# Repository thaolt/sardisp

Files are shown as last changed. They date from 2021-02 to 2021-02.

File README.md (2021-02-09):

# sardisp

## Content

  * [What is it?](#what-is-it)
  * [Installation](#installation)
    + [Windows](#windows)
    + [Linux](#linux)
  * [How to use](#how-to-use)
    + [avrdude](#avrdude)
    + [AVRDUDESS](#avrdudess)
    + [Arduino IDE](#arduino-ide)
  * [Tools](#tools)
  * [Schematic](#schematic)
  * [Perf-board implement](#perf-board-implement)
  * [References](#references)

## What is it?

DIY Simple Arduino In-System-Programmer (aka perf-board USBasp clone)

## Installation

### Windows

**Driver installation**

Please read:

* https://zadig.akeo.ie/
* https://electronics.stackexchange.com/questions/416714/avrdude-does-not-recognize-usbasp-device/417509#417509

Or download:

https://raw.githubusercontent.com/thaolt/sardisp/master/drivers/usbasp_signed.zip

### Linux

Linux doesn't need driver installation

However, it would be more convenient to allow current user access USB instead of execute commands under `root` or `sudo`

If you ever run these steps before, they don't need to be executed again

`$USER` is your current login name on your machine

```
sudo adduser $USER dialout
sudo adduser $USER tty
sudo adduser $USER plugdev
```

Then log out of current desktop session and log in again, it's done.

## How to use

Any software / IDE support USBasp programmer

### avrdude

```
avrdude -u -c usbasp -P usb ...
```
### AVRDUDESS

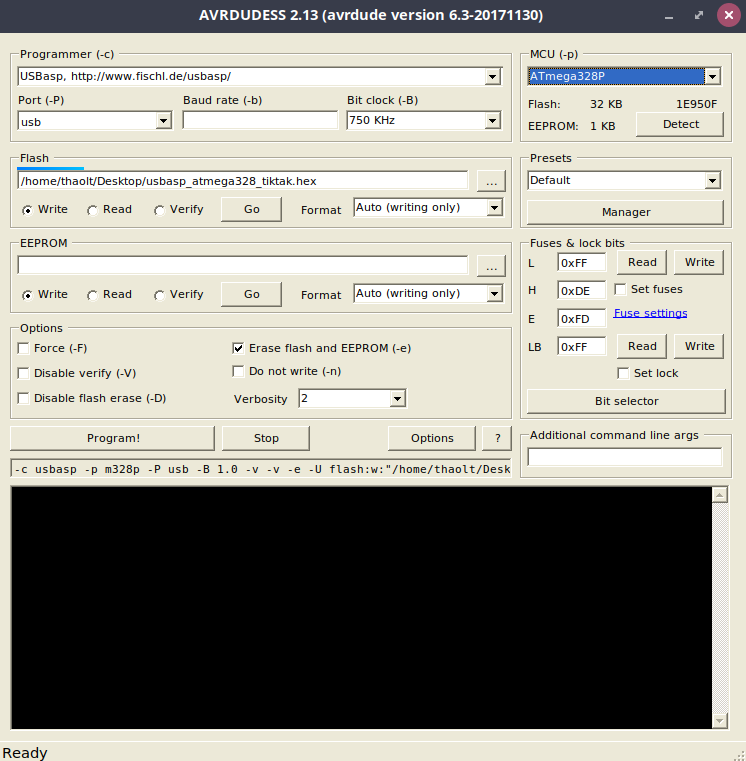
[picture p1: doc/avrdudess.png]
avrdudess usbasp


### Arduino IDE

`Tools` > `Programmer` > `USBasp`

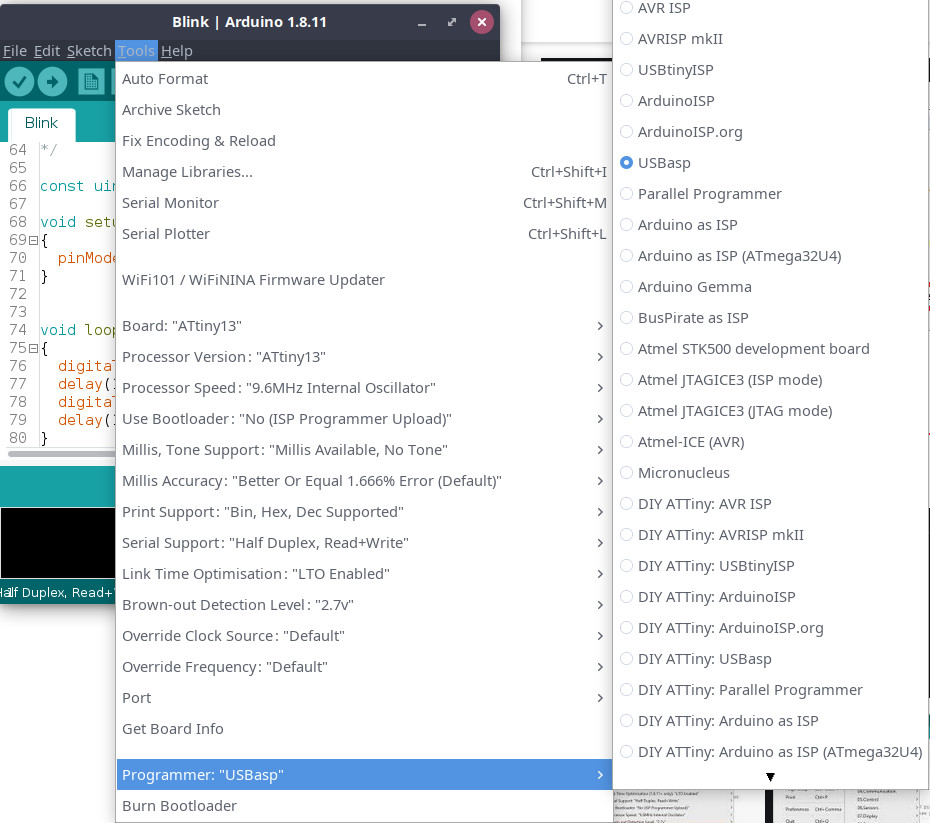
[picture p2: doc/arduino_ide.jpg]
arduino ide usbasp


## Tools

* **Kicad PCB** software is used for making perf-board design easier. https://kicad.org/
* **AVRDUDESS** is a GUI software for avrdude for flashing the firmware, works on Windows, Mac, Linux. https://blog.zakkemble.net/avrdudess-a-gui-for-avrdude/

## Schematic

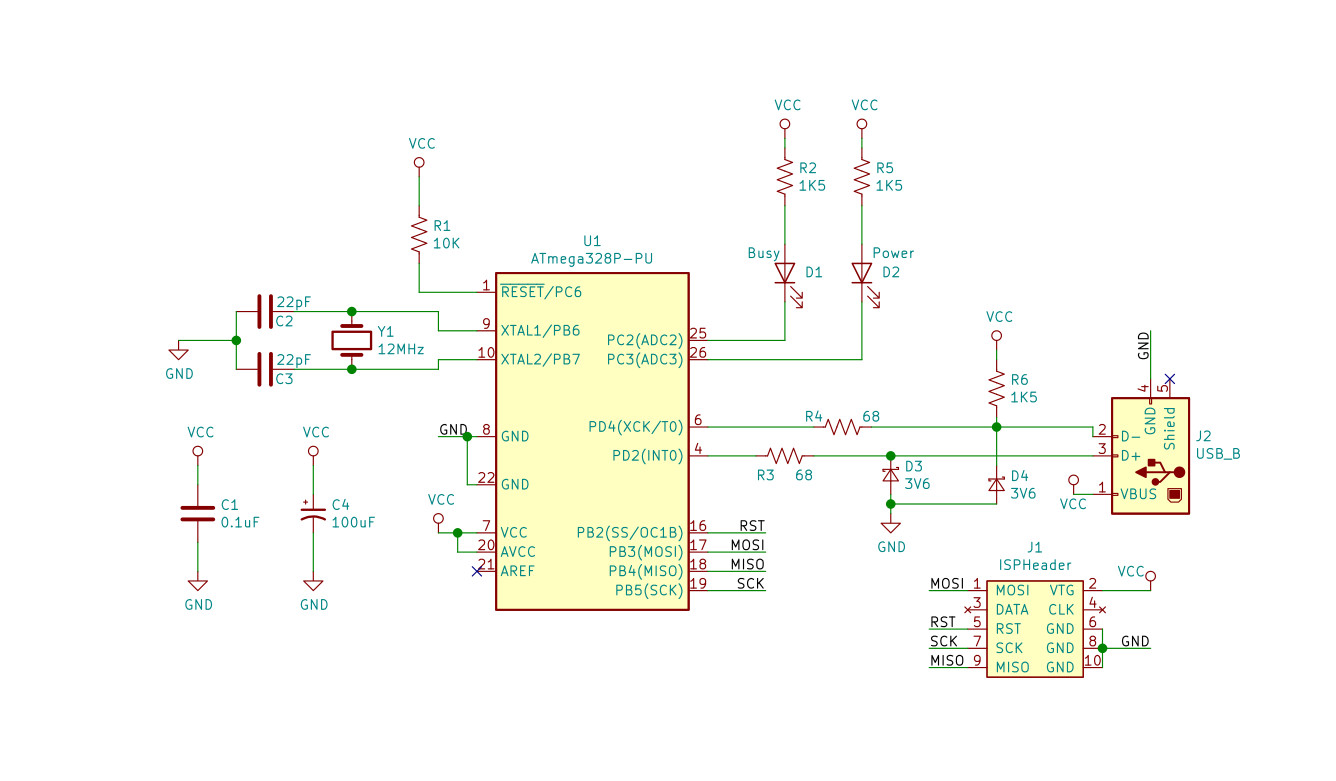
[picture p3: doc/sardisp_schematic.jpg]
sardisp schematic


## Perf-board implement

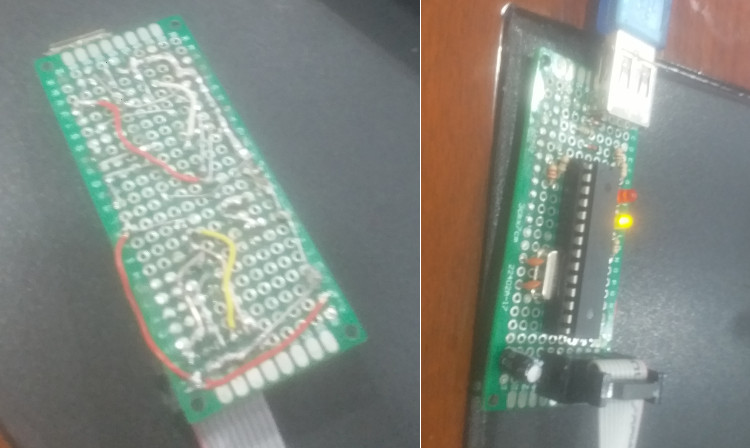
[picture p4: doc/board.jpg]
sardisp board


## References

* https://www.fischl.de/usbasp/
* https://github.com/obdev/v-usb
* https://hackaday.io/project/27401-creative-repairs-and-hacks/log/156127-replacing-an-atmega8-with-a-atmega328p-on-a-usbasp-board
* https://tiktakx.wordpress.com/tag/diy-usbasp-using-atmega-328/

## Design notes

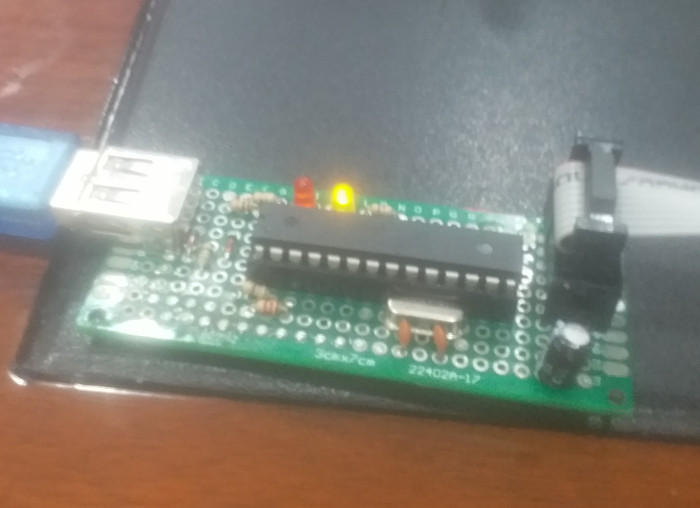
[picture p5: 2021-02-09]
doc/boardup.jpg

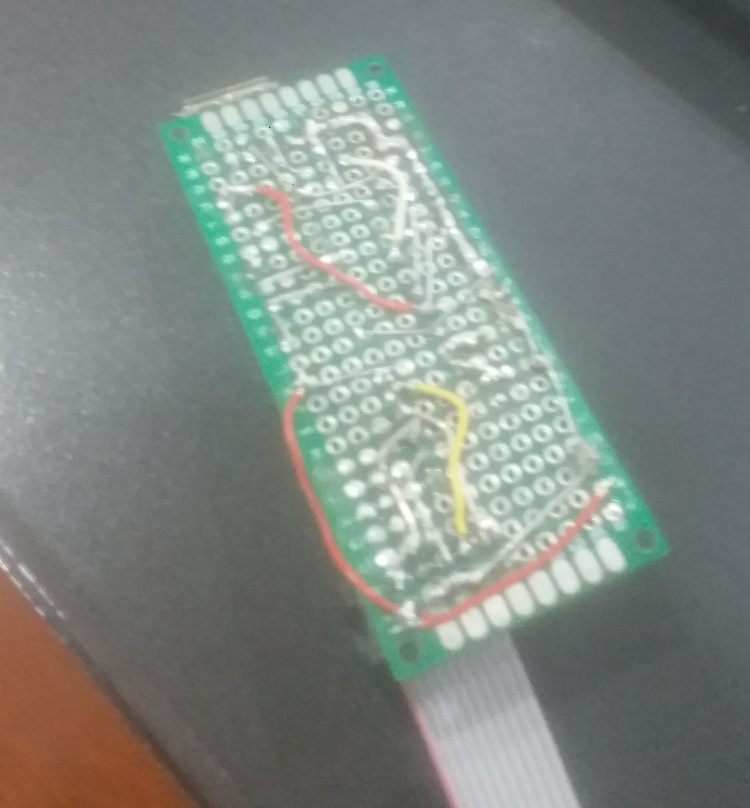
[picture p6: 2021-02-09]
doc/boarddown.jpg

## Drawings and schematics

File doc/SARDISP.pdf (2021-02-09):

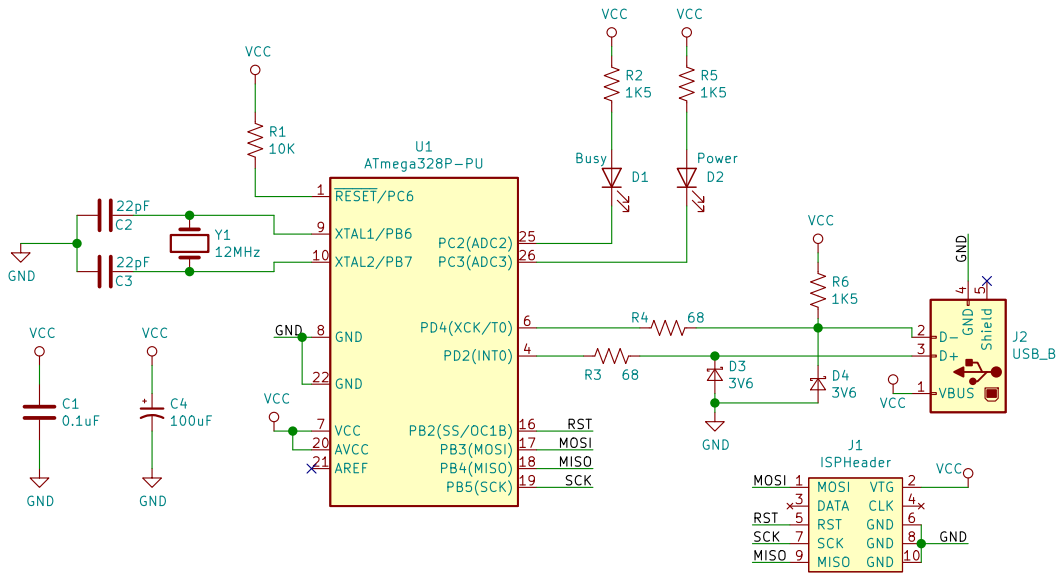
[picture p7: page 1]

Id: 1/1 Title: File: SARDISP.sch Sheet: /

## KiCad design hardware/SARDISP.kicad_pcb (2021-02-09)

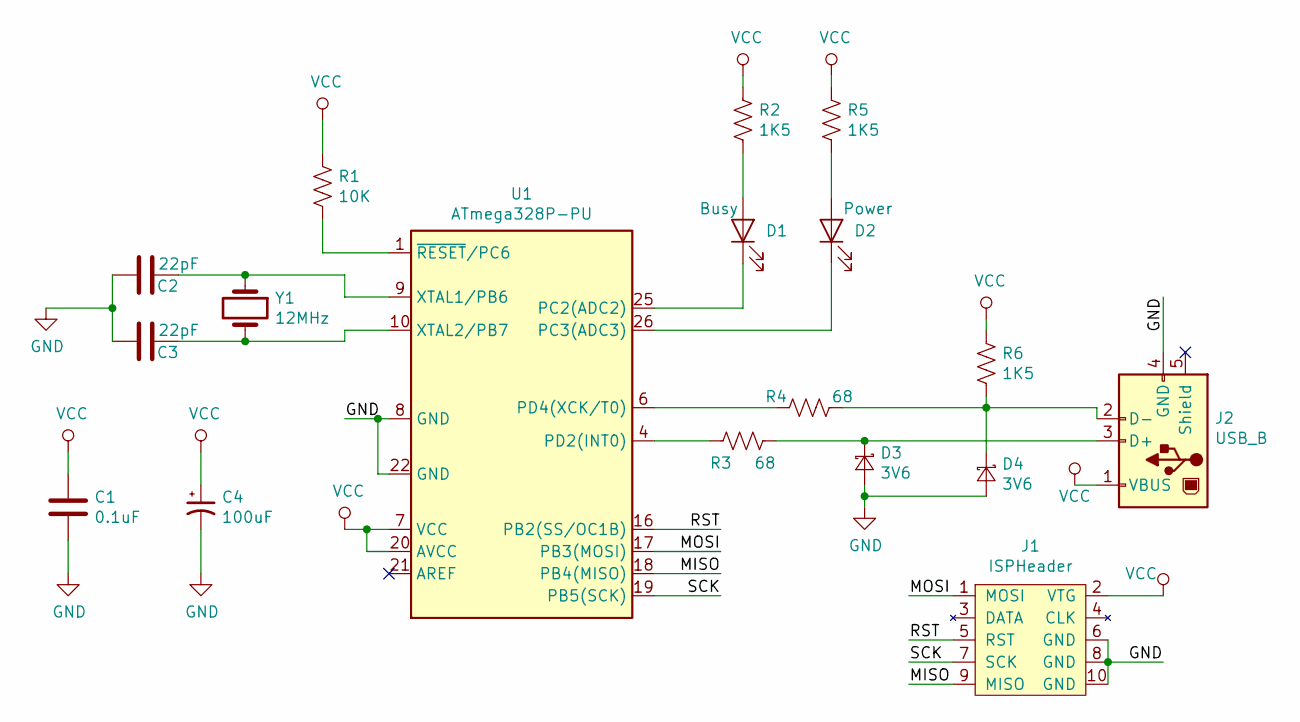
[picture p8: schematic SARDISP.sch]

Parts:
C1: 0.1uF; C_Disc_D3.0mm_W1.6mm_P2.50mm
C2, C3: 22pF; C_Disc_D3.0mm_W1.6mm_P2.50mm
C4: 100uF; CP_Radial_D5.0mm_P2.50mm
D1: Busy; LED_D3.0mm
D2: Power; LED_D3.0mm
D3, D4: 3V6; D_A-405_P7.62mm_Horizontal
J1: ISPHeader; IDC-Header_2x05_P2.54mm_Horizontal
J2: USB_B; USB_A_Stewart_SS-52100-001_Horizontal
R1: 10K; R_Axial_DIN0204_L3.6mm_D1.6mm_P7.62mm_Horizontal
R2, R5, R6: 1K5; R_Axial_DIN0204_L3.6mm_D1.6mm_P7.62mm_Horizontal
R3, R4: 68; R_Axial_DIN0204_L3.6mm_D1.6mm_P7.62mm_Horizontal
U1: ATmega328P-PU; DIP-28_W7.62mm
Y1: 12MHz; Crystal_HC18-U_Vertical

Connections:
/MISO: J1.9 (MISO), U1.18 (PB4(MISO))
/MOSI: J1.1 (MOSI), U1.17 (PB3(MOSI))
/RST: J1.5 (RST), U1.16 (PB2(SS/OC1B))
/SCK: J1.7 (SCK), U1.19 (PB5(SCK))
GND: C1.2, C2.2, C3.2, C4.2, D3.2 (A), D4.2 (A), J1.6 (GND), J1.8 (GND), J1.10 (GND), J2.4 (GND), U1.8 (GND), U1.22 (GND)
unnamed: C2.1, U1.9 (XTAL1/PB6), Y1.1
unnamed: C3.1, U1.10 (XTAL2/PB7), Y1.2
unnamed: D1.1 (K), U1.25 (PC2(ADC2))
unnamed: D1.2 (A), R2.2
unnamed: D2.1 (K), U1.26 (PC3(ADC3))
unnamed: D2.2 (A), R5.2
unnamed: D3.1 (K), J2.3 (D+), R3.1
unnamed: D4.1 (K), J2.2 (D-), R4.2, R6.2
unnamed: R1.2, U1.1 (~RESET~/PC6)
unnamed: R3.2, U1.4 (PD2(INT0))
unnamed: R4.1, U1.6 (PD4(XCK/T0))
VCC: C1.1, C4.1, J1.2 (VTG), J2.1 (VBUS), R1.1, R2.1, R5.1, R6.1, U1.7 (VCC), U1.20 (AVCC)

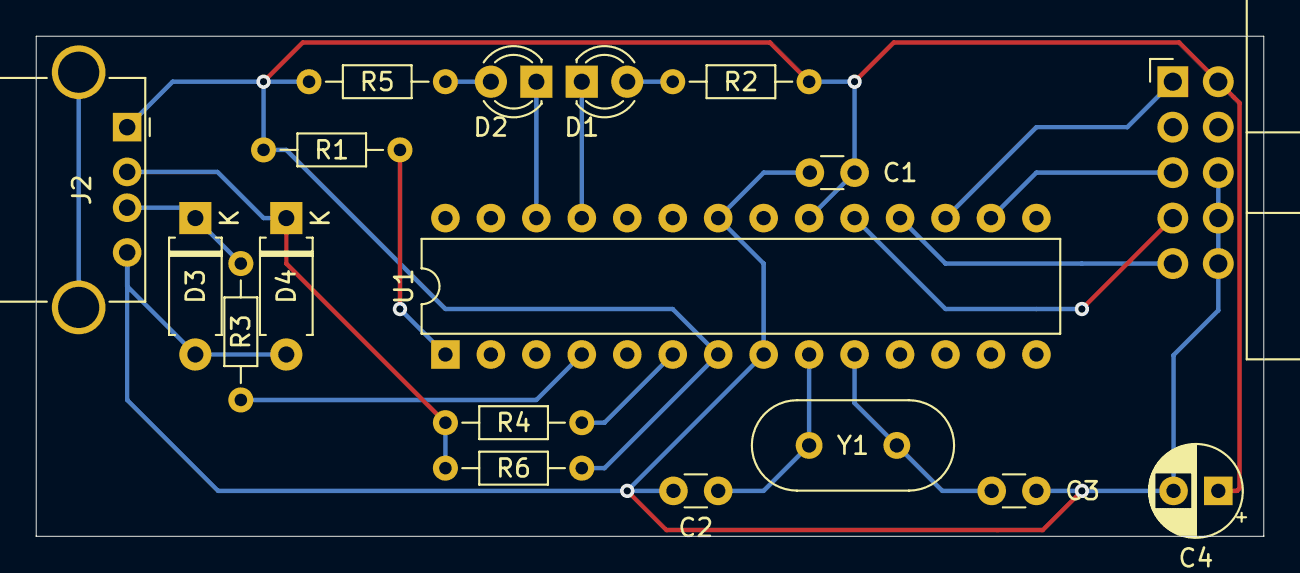
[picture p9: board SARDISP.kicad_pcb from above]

Board: 2 copper layers, 68.6 x 27.9 mm, 18 parts (0 on the bottom side), 17 nets.

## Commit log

2021-02-09 intial commit
    [SARDISP.kicad_pcb, SARDISP.sch]
2021-02-09 added pictures
    [SARDISP.kicad_pcb, SARDISP.sch]
2021-02-09 added windows signed drivers
